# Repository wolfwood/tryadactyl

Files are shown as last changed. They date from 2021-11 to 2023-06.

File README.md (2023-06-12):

# What Is Try-A-Dactyl?
The goal of this project is to be a flexible API for generating ortholinear-ish (column-staggered) keyboards, and particularly split, concave keyboards often called [Dactyls](https://github.com/adereth/dactyl-keyboard). You can start with my preferred keyboard and modify it to your needs, or use the API to build your own 'from scratch' without the pain of re-writing the details you don't care about.

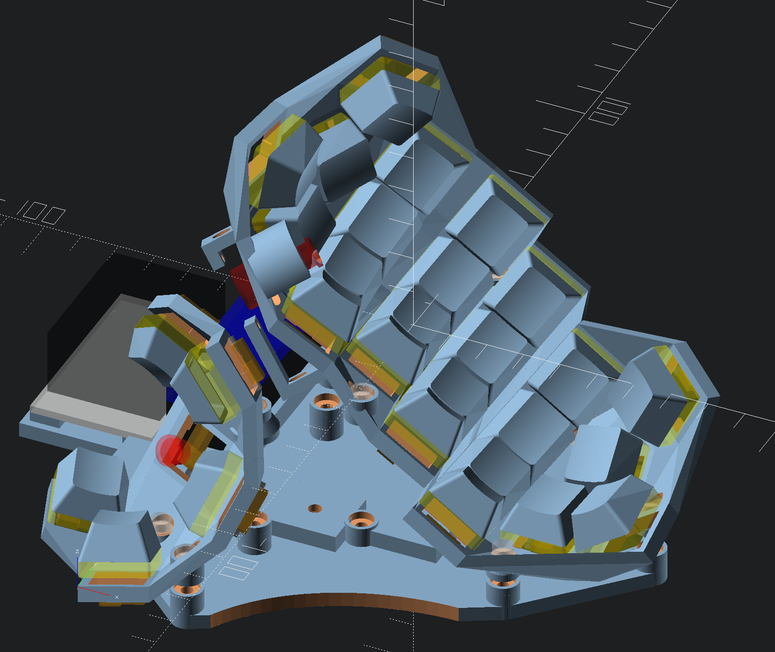
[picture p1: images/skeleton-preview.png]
skeleton-edition style preview


## Why Is TryÅdactyl Different
This project starts with the assumption that one-size does *not* fit all, and so a keyboard user will want to tune their dactyl to achieve the greatest comfort possible. In this process, a number of design-print-test iterations will be required and while the process of 3D printing can be a significant time delay, beyond a certain point its not possible to spend extra time designing and avoid the need to print and test. Given this, it makes sense to optimize the modeling software for faster iteration time at both the design and print level, and to expose both easy configuration for bootstrapping and more fine-grained control for tuning. This way you can Try All (the) Dactyls!

  * faster previews - writing in pure OpenSCAD lets us see changes as fast as possible, rather than using a generator-style binding with a more traditional programming language that must be executed (and possibly compiled) before changes will be visible
  * faster prints - support for multiple case styles allows quicker turn around with more open models like the [Dactyl Manuform Skeleton Edition](https://github.com/atsuyuki/dactyl-manuform-skeleton-edition-4x5)-inspired case, and then the ability to print the same layout with a more protected case with sidewalls when you've settled on a design
  * placement in terms of the keycap tops, not the key switch holders - control where you want your fingers to be, not where the switches go; this means you can keep the same exact layout and change from e.g. Cherry profile to DSA (provided the keycaps don't collide)
  * all parameters correspond to measurable quantities - combined with the above, makes it easier to say things like "I want to move the equals key 2 mm closer to my pinkie" and get the results you want
  * library / API style approach - gives you the tools to build what *you* want, and makes it easy to plug in different keyswitch / keycap styles without having to rewrite half the code
  * no post-processing needed - it should be easier to incorporate unanticipated additions directly in OpenSCAD than to take an *.stl* and munge it somewhere else

I also aim to document an easy approach to handwiring that both simplifies the initial process and allows easy reuse of the electronics as you switch from case to case. [You can find a brief summary here](docs/wiring.md).

## How Does My Personalized Tryadactyl Stand Out?
  * uses sculpted Cherry keycaps as though they are a flat profile
  * concave, spherical thumb cluster, with a 5-way nav switch
  * **Trackpoint!**
  * spherical "pair" of columns under pinkie and index, with lowest key in the outside column moved to the homerow, one column further out
    * on the index, this makes room for the trackpoint without cutting keycaps
	* on the pinkie this makes for a more comfortable extension of the finger to the side to press shift, rather than curling up and pressing down and out
  * recessed magnets in the base plate, to hold the keyboard firmly to an adjustable metal tray. [I documented my approach for mounting peripherals to my chair arms here](https://wolfwood.github.io/chair-arm-keyboard-mounting/).

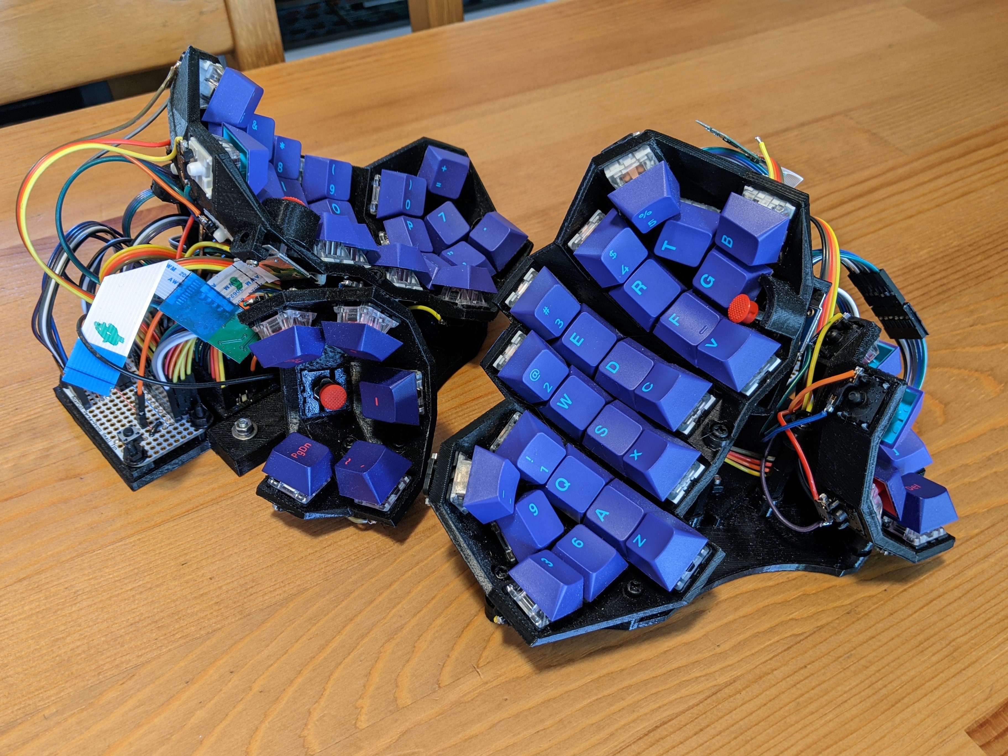
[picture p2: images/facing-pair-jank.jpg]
first full build


## Cool Software Features
  * orthogonal row/column placement styles including flat and cylindrical (cylindrical row + cylindrical column == spherical placement of thumb keys, for example)
  * pluggable support for new placement styles (spirals anyone?)
  * ability to automatically place things (like trackpoints, screws, and support struts) at the corners between keys so they don't collide with switches and keycaps, even when using complex placements
  * pluggable keycap support (add a new profile with a single function)
  * pluggable switch support
  * per-key configuration overrides
    * stick a Row 1 key next to a Row 4 key seamlessly by changing keycap profile row
    * Favorite keycaps don't come with an ortho/ergo kit? Use 'traditional' wide modifier keys with you non-row staggered design by setting a position offset.
  * multiple case styles, automatically generated base plates, and easy manual tuning of strut or wall placement
  * visual indications in preview-mode for identifying keycap collisions (including key travel, when pressed) or hotswap socket collisions with the model or each other

# Organization of the Code
These are abbreviated descriptions of what lives where. See the linked files for detailed documentation comments.

  * **Keys** - the most basic building blocks of a keyboard (you are unlikely to need these directly)
    * [key/mount.scad](key/mount.scad) - The `key_mount()` is the basic switch holder. there are also various bounding boxes around the sides of the keywell used to stitch keywells together into a switch plate, and to generate sidewalls for a case when desired.
	* [key/cap.scad](key/cap.scad) - The `keycap()` model manages caching of pre-rendered *.stl*s when possible and by default hides the caps when rendering a keyboard for printing.  `position_flat()` orients a `keycap()`, or `key_mount()` with the origin at the center of the top of the keycap. `effective_rows()` produces the data structure used to map row/column indexes to keycap profile rows used by a given layout, such as a keyboard without number row that uses only R2, R3, R4.

  * **Columns** - the main unit of organization for our designs, one or more columns per finger
  	* [column/layout.scad](column/layout.scad) - `layout_columns(rows, cols, homerow, homecol, ..., keys, wells, walls, ..., params)` is the main module exposed to the user for creating a keyboard. It creates a connected plate of `cols` key columns with `rows` rows. The `homerow` and `homecol` give the coordinates of the key that is centered on the origin. This is mostly important for curved placements. The boolean `keys` can be used to disable display of keycaps in previews, `wells` controls generation of the switch plate, and `walls` controls the creation of walls, which are independent of the switch plate. The booleans `leftwall`, `rightwall`, `topwall` and `bottomwall` control a separate way to generate simple, regular walls that are reasonable for flat keyboards with a shallow tent and tilt. A `wall_matrix` may be specified instead to give per-key control of the wall sides and distance (including multiple articulation points). The params struct is generated by the function below.
    * [column/util.scad](column/util.scad) - The function `layout_placement_params()` produces a pseudo-struct containing all the user supplied configuration parameters, for convenience. `layout_placement()` is the low level module all the higher level APIs use to uniformly place child modules at row, column coordinates, using the placement_params. The functions `create_flat_placement()` and `create_circular_placement()` create structs passed to `layout_placement_params()` for row or column alignment. The flat placement take an [x, y] pair (or vector of pairs, or vector of vector of pairs) specifying distance in millimeters. The circular placement takes a [chord, radius, angle] triplet (or vectors thereof) specifying the relationship between two points on a circle, using any two of: the the shortest-line distance between the points (a *chord*), the radius of the circle, or the angle between the two points from the center of the circle. `normalize_chord()` calculates the missing parameter from the other two, but should be automatically called anywhere a chord is accepted to sanitize the input. If a single value is provided to these functions, the spacing between successive rows or columns will be uniform. If a vector of values are provided, the distance used for each successive row or column relative to the previous can be tweaked. using a vector of vectors allows it to vary both per-row and per-column. missing rows, or columns, will be substituted with the last specified value. The `optional_vector_index()` automates this lookup-with-substitution process. `optional_index()` is the version used for scalars, like `rows`.

  * **Accessories**
    * [assembly/rest.scad](assembly/rest.scad) - `wrist_rest_base()` is the model for @crystalhand's holder for a silicone palmrest. this file invokes it and adds mounting dimples for rubber feet and a flush mount for a bar-shaped cup magnet. (**TODO** add @kennykaye style rest)
	* [assembly/trackpoint.scad](assembly/trackpoint.scad) - `install_trackpoint(row, col, ... displacement, params, ... use_shield ...)` places a mount for a trackpoint so that the stem rises through the intersection between keys nearer to the `homerow` and `homecol` of the key specified by `row` and `col`. `displacement` can be used to tweak this positioning without having to modify the `params` used for the rest of the switch plate. `h1` and `h2` can be used to move the arms of the trackpoint mount so they contact the switch plate and don't collide with the switches. `use_shield` enables a  cylindrical covering to protect the trackpoint stem extension, if the trackpoint is not fully encircled by keys.
	* [util.scad](util.scad) - utilities for hulling sets of modules while preserving their concavities; utilities for mounting magnets, rubber feet, microcontrollers, and other electronics.

  * **Keyboards**
	* [settings.scad](settings.scad) - controls various parameters mostly pertaining to key caps, switches, spacing and rendering settings
    * [assembly/util.scad](assembly/util.scad) - the `screw_mounting()` module and associated `screw_mounting_params()` function for adding screw-attached support struts between switch plate and base plate
	* [assembly.scad](assembly.scad) - my personal skeleton-edition style keyboard
	* [debug-new-walls.scad](debug-new-walls.scad) - my closed-case keyboard experimentation

# Usage
To view the keyboard assembled, run `openscad assembly.scad`. This is how I normally make edits. Within [assembly.scad](assembly.scad) the base plate is generated in debug mode which just shows the strut mount placement, so that strut heights can be manually adjusted, and so that renders are faster. To see the full keyboard, find the line `base_plate(debug=true);` and change to `false`.

For printing, the `assembly/fingers.scad`, `assembly/plate.scad` and `assembly/thumb.scad` models can be used to obtain separate parts. trying to print the whole assembly as is would be unlikely to succeed. I like to use the commandline to invoke `openscad` for renders, like the following: `openscad -q --hardwarnings --render -o things/plate.stl assembly/plate.scad`.

To validate that changes to the library code have not introduced regressions, run `make test` prior to editing (or after a `git stash`), which will generate reference *.stl*s for later comparison. Run `make test` again after editing to see if the tests still produce identical *.stl*s. New tests should be added when new positioning functions, keycap profiles, or other features are introduced. The tester models should also be useful to those who might like to print a smaller model to consider the feel of a given column shape without wasting time and material printing a full keyboard.

Right now testing is a bit fiddly. Edit `testers/wrapper.py` to point `SCAD_EXE` at a nightly build of openscad, which has the *sort-stl* feature. Even with that, *.stl* files aren't always consistent. The alternative approach also has issues. Blog post incoming :)

# FAQs
#### Q
  Why not just use a flat keycap profile and save yourself a lot of work?

#### A
  0. Using a flat profile doesn't actually solve the problem. For example, when you do cylindrical placement of the switch holders, rather than the keycap top surfaces, the radius does not correspond to measurements of the fingers and their movement. The radius is longer because the height of the switch and keycap can be a sizable percentage of the finger length. Rather than calculating this offset manually, it makes sense for the software to make the compensation for you.

  1. I'm not aware of a cylindrical topped (rather than spherical) flat MX profile, which I prefer.

  2. Sculpted profiles tend to have angled sides, and top surfaces that are noticeably smaller than a full 1u footprint, which lets you pack them a bit more tightly if you aren't looking for a full 19.05 mm spacing between keys. This also seems particularly important for the spherical key placement i use, because its more at risk of keycap collisions than cylindrical. However, I haven't yet investigated the spherical placement with a flat profile, so maybe it's less of a concern than it seems.

  3. Many colorways are limited to specific (sculpted) profiles. I started this project after being completely blown away by the [GMK Copper renders](https://geekhack.org/index.php?PHPSESSID=6mre0fhdltin70p68o5i6feekgqu2082&action=dlattach;topic=102917.0;attach=229851;image), for example.

  4. Flexibility: my design can accommodate flat profiles. It may even give the most pleasing results that way. It can also accommodate sculpted profiles. It could even be used to add a sculpted effect to a flat profile (or change the sculpt of a sculpted profile). To each their own, as they say.

  5. Cherry profile R3 has a lower vertical height that DSA or XDA. Obviously chocs are a superior choice for low profile switches, but I don't like linear switches and I love my Kailh Speed Copper switches, so Cherry profile helps me shave off some height.

# TODO
  * key (profile & switch/well) configuration architecture
    - [ ] add and test SA profile support
    - [ ] add and test DSA profile support
    - [ ] parameterize switch (choc, void, ???)
	  - [ ] use this to support SKRH and RKJXS nav switches instead of profile row?
	  - [x] expand `mxstem()` to incorporate switch type
	  - [x] how to generalize `innerdia`, `outerdia` and `thickness`
      - [ ] separate keywell use of `spacer()` from assembly.scad level use
        - [ ] think about automatic decisions about using minimum keywell dimension vs being wide enough to prevent hull from colliding with 1U keycap vs wide keycap support vs being as wide as whatever the keyspacing is to maybe avoid hulling if adjacent key is the same profile and has identical positioning (tent/tilt/offset etc.)
	- [ ] test traditional modifier key support
	  - [ ] add concept of key width or is using offset good enough?
  * columns
    - [ ] document layout_columns arguments
	- [ ] spiral placement
	- [ ] figure out how to connect 2 rectangles (faces of a keywell) in 3D space without hull ([functional OpenSCAD](https://github.com/thehans/FunctionalOpenSCAD) seems like a good bet, or BOSL2?)
	  - [ ] alternatively use the corner sphere bounding boxes for _everything_ to guarantee thickness and accept the cost (and figure out how to avoid colliding with keycap)
  * case
    - [ ] finish closed case
	  - [ ] join the walls of each finger's switch plate
	  - [ ] consider bridging over some keys on the sides
	  - [ ] generate closed case base plate
	- [ ] add cylindrical perimeter to skeleton-edition case
	- [ ] support raised perimeter bezel
	- [ ] more wall code cleanup
	- [ ] hack up and test a @kennykaye-esque palmrest? use JellyTitan magnetic feet?
  * general
    - [x] reorganize code into directories?
	- [ ] re-locate util functions
	- [x] rename `keywell()` to ???`switch_holder()`??? to reflect that keywell is generally accepted to mean concavity
    - [ ] decide how multiple case style support and rendering of individual parts can be generalized

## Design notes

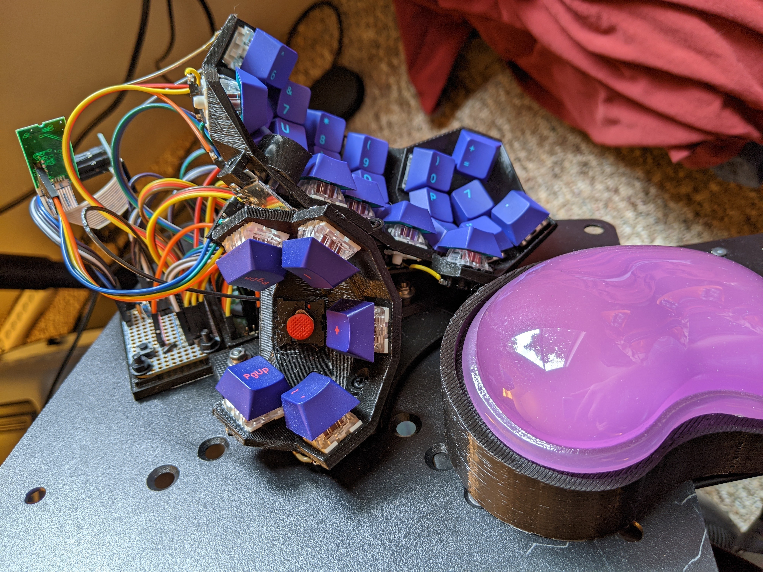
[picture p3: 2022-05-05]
images/jank.jpg

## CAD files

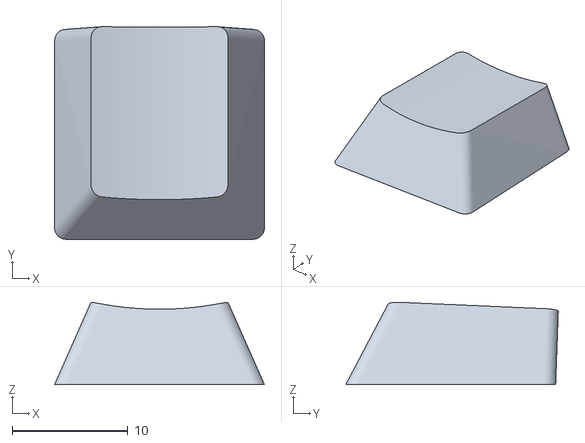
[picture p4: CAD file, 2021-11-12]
key/prerendered/cherry/2.stl
18.2 x 18.4 x 7.13

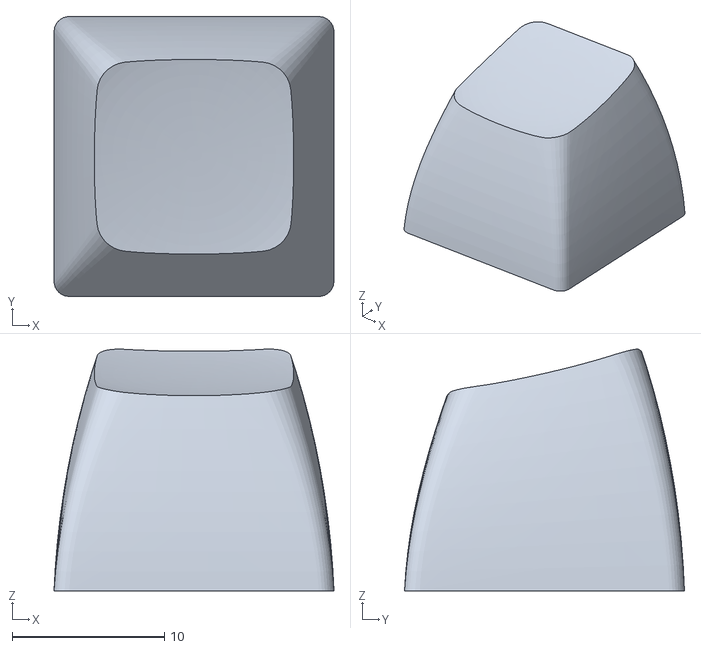
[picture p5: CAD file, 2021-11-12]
key/prerendered/sa/1.stl
18.4 x 18.4 x 15.9

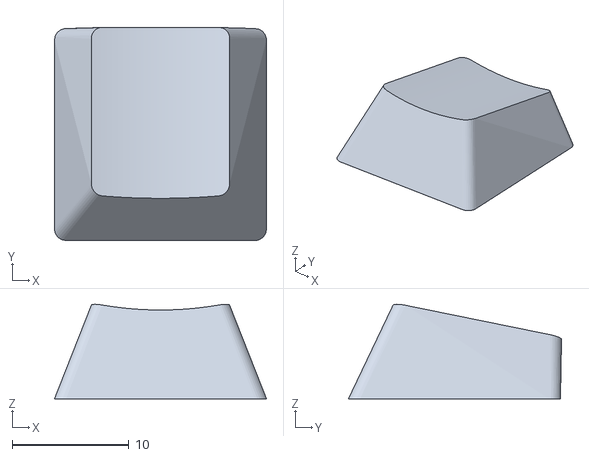
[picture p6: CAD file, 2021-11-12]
key/prerendered/cherry/5.stl
18.2 x 18.3 x 8.10

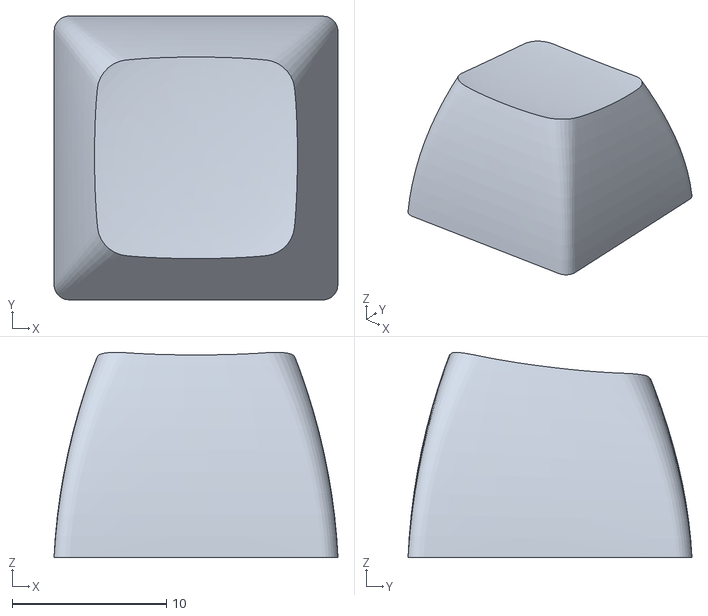
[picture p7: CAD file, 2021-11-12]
key/prerendered/sa/4.stl
18.4 x 18.4 x 13.3

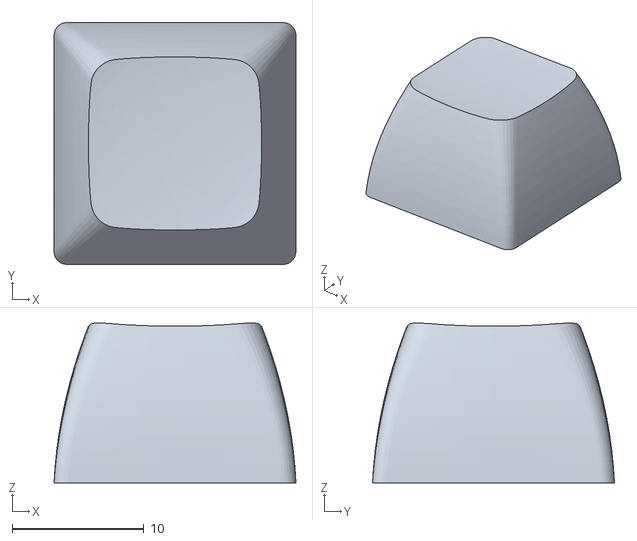
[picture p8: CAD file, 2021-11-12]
key/prerendered/sa/5.stl
18.4 x 18.4 x 12.2

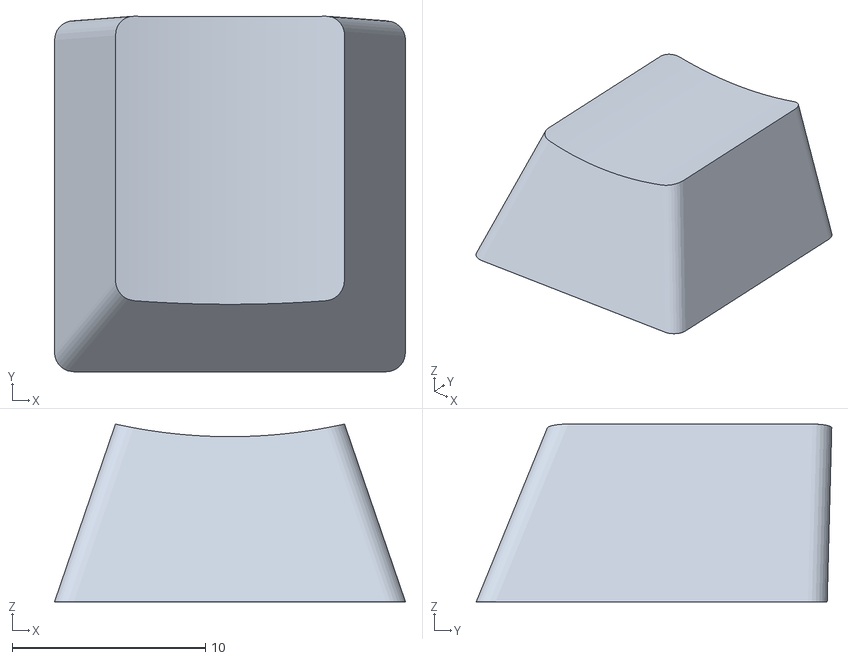
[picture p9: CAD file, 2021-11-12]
key/prerendered/cherry/1.stl
18.2 x 18.4 x 9.20

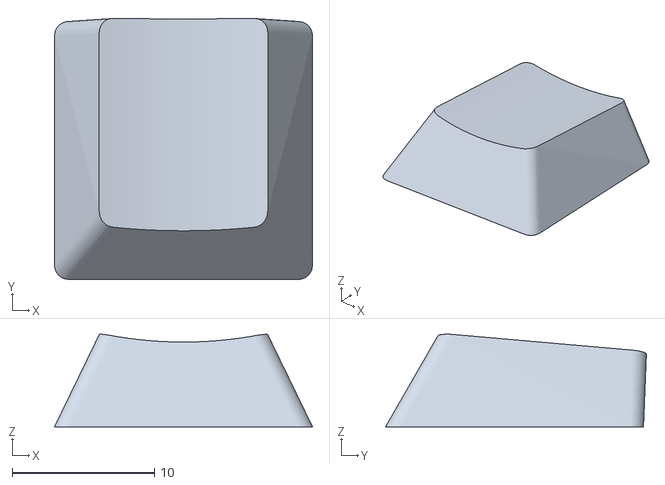
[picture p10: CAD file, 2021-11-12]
key/prerendered/cherry/3.stl
18.2 x 18.4 x 6.52

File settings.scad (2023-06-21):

/* keycaps */
_profile = "cherry";

// the height of the bottom of the keycap over the key_mount.
// a property of the keycap but I couldn't think fo a better name.
// shouldn't need to override this directly, but you can.
//_stem_height = 6.1;

// keycap render settings

/* Pre-rendered keycaps are recommended as they should be much faster, and remove the dependency on KeyV2.
 * However they lose the distinctive coloring. Also, pre-renders may be missing. Used in both previews and renders.
 */
_prerendered_keycaps = true;

// if not pre-rendering, these options turn down the fidelity so that previews/renders don't take so long
_fast_keycap_preview = true;
_fast_keycap_render = false;

// don't show keycaps in renders. we don't want keys when 3D printing, also they block the view and can be slow
_disable_keycap_render = true;


/* keyswitch */
// switch style is "mx", "choc".
// can be inferred from profile
//_switch_style= "choc";

// if using mx switches, are they speed switches (lower travel)?
//_mx_speed = true;

// how far the key switch can depress (only for visual indication, doesn't affect the keyboard)
// can be inferred from switch type
//_switch_travel = 4.0;


/* key_mount parameters */
// innerdia is the (square) hole for the switch
// outerdia is the the minimum structural support
_mx_innerdia = 13.9;
_mx_outerdia = 17;

_choc_innerdia = 13.8;
_choc_outerdia = 15.5;

// key plate thickness
// can be inferred from switch type
//_thickness=4; // blanket override... probably unnecessary

_mx_thickness = 4;
_choc_thickness = 3;

// MX cutout params
function mx_tab_offset() = 1.2; // how far from the top the switchholders start
function mx_tab_depth() = 0.6; // how far tabs stick out
function mx_tab_width() = 5;

function choc_tab_offset() = 1.2; // how far from the top the switchholders start
function choc_tab_depth() = 0.2; // how far tabs stick out

function mx_and_choc()=false;

_epsilon = .001; // smallest meaningful overlap, used when avoiding coincident faces

// the footprint of the keycaps.
// defines how close key_mounts can be, but mostly used for outer perimeters.
_mx_min_spacing = 18.4;
_choc_min_spacing = 18;

// how much room we need for switchpins, hotswaps, etc.
// used to cut into trackpoint mount supports
function switch_clearance() = 3;


/* side wall width */
_wall_width=2.5;

// extra space between the key mount and an ajoining wall, in x and y
_wall_extra_room = [0,0]; //[5,3];


// bounds
//highest_high=40;
//XXX  eliminate by placing bottom of plate at Z=0
function lowest_low() = 60;

// Do Not Edit Below This Line

function profile(override) =
  !is_undef(override) ? override :
  !is_undef($profile) ? $profile :
  _profile;

function profile_is_uniform() =
  profile() == "dsa" || profile() == "g20" || profile() == "lpx";


function stem_height() =
  !is_undef($stem_height) ? $stem_height :
  !is_undef(_stem_height) ? _stem_height :
  profile() == "cherry" ? 6.1 :
  profile() == "sa" ? 6.8 :
  profile() == "lpx" ? 5 :
  assert(false, "unrecognized keycap profile");


function prerendered_keycaps() = !is_undef($prerendered_keycaps) ? $prerendered_keycaps : _prerendered_keycaps;
function fast_keycap_preview() = !is_undef($fast_keycap_preview) ? $fast_keycap_preview : _fast_keycap_preview;
function fast_keycap_render() = !is_undef($fast_keycap_render) ? $fast_keycap_render : _fast_keycap_render;
function disable_keycap_render() = !is_undef($disable_keycap_render) ? $disable_keycap_render : _disable_keycap_render;

function switch_type() =
  !is_undef($switch_type) ? $switch_type :
  !is_undef(_switch_type) ? _switch_type :
  profile() == "lpx" || profile() == "mbk" || profile() == "cs" || profile() == "mcc" ? "choc" :
  profile() == "cherry" || profile() == "sa" || profile() == "dsa" || profile() == "g20" ? "mx" :
  assert(false, str("unknown profile '", profile(), "' cannot deduce switch_type"));

function mx_speed() =
  !is_undef($mx_speed) ? $mx_speed :
  !is_undef(_mx_speed) && _mx_speed;

function switch_travel() =
  !is_undef($switch_travel) ? $switch_travel :
  !is_undef(_switch_travel) ? _switch_travel :
  switch_type() == "mx" ? mx_speed() ? 3.5 : 4.0 :
  switch_type() == "choc" ? 3.0 :
  assert(false, str("unknown switch_type '", switch_type()));

function innerdia() =
  !is_undef($innerdia) ? $innerdia :
  switch_type() == "mx" || (mx_and_choc() && switch_type() == "choc") && !is_undef(_mx_innerdia) ? _mx_innerdia :
  switch_type() == "choc" && !is_undef(_choc_innerdia) ? _choc_innerdia :
  assert(false, str("please define an innerdia for: ", switch_type()));

function outerdia() =
  !is_undef($outerdia) ? $outerdia :
  switch_type() == "mx" && !is_undef(_mx_outerdia) ? _mx_outerdia :
  switch_type() == "choc" && !is_undef(_choc_outerdia) ? _choc_outerdia :
  assert(false, str("please define an outerdia for: ", switch_type()));

function spacer() =
  !is_undef($spacer) ? $spacer :
  switch_type() == "mx" ? _mx_min_spacing - outerdia() :
  switch_type() == "choc" ? _choc_min_spacing - outerdia() :
  assert(false, str("please define an spacer for: ", switch_type(), " or: ", profile()));

function thickness() =
  !is_undef($thickness) ? $thickness :
  !is_undef(_thickness) ? _thickness :
  switch_type() == "mx" ? _mx_thickness :
  switch_type() == "choc" ? _choc_thickness :
  assert(false, "please define a key plate thickness");

function wall_width() =
  !is_undef($wall_width) ? $wall_width :
  !is_undef(_wall_width) ? _wall_width :
  assert(false, "please defined a wall_width");

function wall_extra_room() =
  !is_undef($wall_extra_room) ? $wall_extra_room :
  !is_undef(_wall_extra_room) ?
  !is_list(_wall_extra_room) ? [_wall_extra_room, _wall_extra_room]
  : _wall_extra_room :
  [0,0];


function epsilon() =
  !is_undef($epsilon) ? $epsilon :
  !is_undef(_epsilon) ? _epsilon :
  assert(false, "please define an _epsilon value");

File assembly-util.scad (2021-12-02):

include <settings.scad>;
use <column-util.scad>;


//keys for param "dictionary"
height_enum = "a";
strut_dia_enum = "b";
screw_dia_enum = "c";
washer_dia_enum = "d";
headroom_enum = "e";
footroom_enum = "f";
spacer_enum = "g";
stay_upright_enum = "h";
//tent_enum = "i";
displacement_enum = "j";
row_enum = "k";
col_enum = "l";
layout_params_enum = "m";
offsets_enum = "n";


// diy stuct for marshalling all the params together
// cylinders are described with a 2D vector, x as diameter and y as height
function screw_mounting_params(row, col, height=20, strut_dia=6.5, screw_dia=3.2, washer_dia=6.4,
			       headroom=[[0,0],[2,7]], footroom=[2,2], spacer=3, stay_upright=true, displacement=[0,0,-15], offsets=[0,0,0], layout_params=default_layout_placement_params()) =
  [[height_enum, height],
   [strut_dia_enum, strut_dia],
   [screw_dia_enum, screw_dia],
   [washer_dia_enum, washer_dia],
   [headroom_enum, headroom],
   [footroom_enum, footroom],
   [spacer_enum, spacer],
   [stay_upright_enum, stay_upright],
   //[tent_enum, tent],
   [displacement_enum, displacement],
   [offsets_enum, offsets],
   [row_enum, row],
   [col_enum, col],
   [layout_params_enum, layout_params]];

default_screw_mounting_params = screw_mounting_params();


module screw_mounting_blank(params, idx) {
  strut_dia = match(strut_dia_enum, params);
  screw_dia = match(screw_dia_enum, params);
  washer_dia = match(washer_dia_enum, params);
  headroom = optional_vector_index(match(headroom_enum, params), idx);
  footroom = optional_vector_index(match(footroom_enum, params), idx);
  spacer = optional_index(match(spacer_enum, params), idx);

  rotate([idx*180,0,0]) {
    headroom_dia = washer_dia + headroom.x;
    footroom_dia = strut_dia + footroom.x;
    // envelops screwhead and washer
    cylinder(h=headroom.y, d=headroom_dia);
    /* washer sit on this, and it 'spaces' out the cuts for the washer and the strut if we need to
     *  avoid cutting into switch plate too deeply */
    translate([0,0,-spacer]) {
      cylinder(h=spacer, d2=headroom_dia, d1=footroom_dia);
      // envelops strut to provice a bit more stability
      translate([0,0,-footroom.y]) {
	cylinder(h=footroom.y, d=footroom_dia);
      }
    }
  }
}

module mount_bounding_box(z, thickness, mounting_params=default_screw_mounting_params) {
  let(row=match(row_enum, mounting_params),
      col=match(col_enum, mounting_params),
      displacement=match(displacement_enum, mounting_params),
      offsets=match(offsets_enum, mounting_params),
      layout_params=match(layout_params_enum, mounting_params),
      strut_dia = match(strut_dia_enum, mounting_params),
      washer_dia = match(washer_dia_enum, mounting_params),
      headroom_0 = optional_vector_index(match(headroom_enum, mounting_params), 0),
      headroom_1 = optional_vector_index(match(headroom_enum, mounting_params), 1),
      footroom_0 = optional_vector_index(match(footroom_enum, mounting_params), 0),
      footroom_1 = optional_vector_index(match(footroom_enum, mounting_params), 1),
      x = max(strut_dia + max(headroom_0.x, headroom_1.x), washer_dia + max(footroom_0.x, footroom_1.x))
      ){

    translate([0,0,z])
      linear_extrude(thickness)
      projection()
      layout_placement(row, col, params=layout_params, offsets=offsets, displacement=displacement,
		       corners=true, flatten=false, stay_upright=true)
      cube([x,x,1],center=true);
  }
}

module screw_mounting(row,col,height, displacement,
		      row_spacing, col_spacing, profile_rows, homerow, homecol, tilt, offsets,
		      mounting_params=default_screw_mounting_params,
		      layout_params, idx=-1, clearance=true, blank=false) {

  module clearance(washer=[6, .55], screwhead=[5.55, 2.55], indicator=0) {
    color("silver", .3) {
      cylinder(d=washer.x, h=washer.y);
      translate([0,0,washer.y]) cylinder(d=screwhead.x, h=screwhead.y);
      if (indicator != 0) {
	translate([0,0,washer.y+screwhead.y]) difference() {
	  cylinder(d=indicator+4, h=.1);
	  cylinder(d=indicator, h=.1);
	}
      }
    }
  }

  let(row=match_override(row_enum, mounting_params, row),
      col=match_override(col_enum, mounting_params, col),
      height=match_override(height_enum, mounting_params, height),
      displacement=match_override(displacement_enum, mounting_params, displacement),
      offsets=match_override(offsets_enum, mounting_params, offsets),
      layout_params=match_override(layout_params_enum, mounting_params, layout_params),
      strut_dia = match(strut_dia_enum, mounting_params),
      screw_dia = match(screw_dia_enum, mounting_params),
      washer_dia = match(washer_dia_enum, mounting_params),
      spacer_0 = optional_index(match(spacer_enum,mounting_params), 0),
      spacer_1 = optional_index(match(spacer_enum,mounting_params), 1),
      headroom_0 = optional_vector_index(match(headroom_enum,mounting_params), 0),
      headroom_1 = optional_vector_index(match(headroom_enum,mounting_params), 1)
      ){

    assert(height==6 || height==10 || height==12 || height==15 || height==16 || height==18 || height==20 ||
	   height==21 || height==22 || height==24 || height==25 || height==26 || height==27 || height==28 || height>=30,
	   "Height must be a combination of 6, 10, 15 and 20 mm struts");

    difference() {
      union() {
	layout_placement(row, col, params=layout_params,row_spacing=row_spacing, col_spacing=col_spacing, profile_rows=profile_rows, homerow=homerow, homecol=homecol, tilt=tilt, offsets=offsets, displacement=displacement,corners=true, flatten=false, stay_upright=true) {
	  $fn=60;

	  if(idx != 1)
	    screw_mounting_blank(mounting_params,0);

	  if (idx != 0)
	    translate([0,0,-height-spacer_0-spacer_1]) {
	      screw_mounting_blank(mounting_params,1);
	    }
	}

	children();
      }

      if (!blank) {
	layout_placement(row, col, params=layout_params, row_spacing=row_spacing, col_spacing=col_spacing, profile_rows=profile_rows, homerow=homerow, homecol=homecol, tilt=tilt, offsets=offsets, displacement=displacement,corners=true, flatten=false, stay_upright=true) {
	  $fn=60;
	  cylinder(h=height,d=washer_dia);

	  let(z=height+spacer_0+spacer_1) {
	    translate([0,0,-(z+.1)]) cylinder(h=z+2*.1, d=screw_dia);
	    translate([0,0,-(z+height+7)]) cylinder(h=height+7, d=washer_dia);
	  }
	  let(z=height) {
	    translate([0,0,-(z+spacer_0)]) cylinder(h=z, d=strut_dia);
	  }
	}
      }
    }

    if ($preview && clearance && !blank) {
      layout_placement(row, col, params=layout_params, row_spacing=row_spacing, col_spacing=col_spacing, profile_rows=profile_rows, homerow=homerow, homecol=homecol, tilt=tilt, offsets=offsets, displacement=displacement,corners=true, flatten=false, stay_upright=true) {
	$fn=60;
	if(idx != 1)	  clearance();
	if(idx != 0)
	  translate([0,0,-(height+spacer_0+spacer_1)]) rotate([180,0,0]) clearance(indicator=washer_dia+headroom_1.x);
      }
    }
  }
}

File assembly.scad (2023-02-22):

use <settings.scad>;
use <key/cap.scad>;
use <column/util.scad>;
use <column/layout.scad>;
use <assembly/trackpoint.scad>;
use <assembly/util.scad>;


rows=4;
cols=2;

homerow=2;
profile_rows=effective_rows(rows,homerow);
tilt=[-3,0,0];
tent=[0,32,0];
row_chord = [14.5,25,0];

// Akko cherry PBT neesds a bit more space
tight_cylindrical_row =[row_chord+[.5/2,0,0],
			 row_chord+[.5,0,0],
			 row_chord,
			 row_chord+[.5,0,0]];


tight_spherical_row = [row_chord+[5.2,0,0],
		       row_chord+[4.75,0,0],
		       row_chord+[4.5,0,0],
		       row_chord+[8.6,0,0]];
tight_spherical_col = [[row_chord+[-1.8,0,0]],
		       [row_chord+[.9,0,0]],
		       [row_chord+[0,0,0]],
		       [row_chord+[-.5,0,0]]];
spherical_z = [4,30,0,0];

index_keys= true;
index_pos = [-(outerdia()+4),-4,6];
index_tent = [0,0,5];
index_tilt = [0,0,0];
index_rows= [rows, rows-1, 1];
index_cols=cols;
index_placement_params =
  layout_placement_params(homerow=[homerow,homerow,0], homecol=0,
			  row_spacing=create_circular_placement([tight_cylindrical_row, tight_spherical_row, [row_chord]]),
			  col_spacing=create_circular_placement(tight_spherical_col, z_correct=spherical_z),
			  profile_rows=[profile_rows,profile_rows,[4]],
			  tent=index_tent+tent, tilt=index_tilt, position=index_pos);

index_mountings = [screw_mounting_params(row=0, col=0, height=60, layout_params=index_placement_params,
					 displacement=[5,-1,-23], offsets=[0,0,-1],
					 headroom=[[10,0], [2,10]], footroom=[[12, 2], [2, 2]]),
		   //screw_mounting_params(row=1, col=0, height=50, layout_params=index_placement_params)
		   screw_mounting_params(row=1, col=0, height=40, displacement=[-11, -1.8, -17],
					 headroom=[[1,2.6], [2,10]], layout_params=index_placement_params)
		   /*screw_mounting_params(row=3, col=0, height=50, layout_params=index_placement_params,
					 headroom=[[1,0],[2,7]],
					 displacement=[2,5,-20])*/
		   ];


middle_keys = true;
//middle_offset = [[0,0,0], [0,4,1]];
middle_offset = [0,5,0];
ring_offset=[1,-5,-1];
middle_rotation = [0,0,0];
middle_placement_params =
  layout_placement_params(homerow=homerow, homecol=1,
			  row_spacing=create_circular_placement(tight_cylindrical_row),
			  col_spacing=create_flat_placement(outerdia()+spacer()),
			  profile_rows=profile_rows,
			  offsets=[ring_offset, middle_offset], tent=tent, tilt=middle_rotation+tilt);
middle_mountings = [screw_mounting_params(row=0, col=0, height=30, headroom=[[1,3],[2,7]], footroom=[[2,0],[2,2]],
					  layout_params=middle_placement_params,
					  /*displacement=[1.3,.4,-15],*/displacement=[0,1.6,-15-3], offsets=[0,0, -4]),
		    screw_mounting_params(row=1, col=1, height=20, layout_params=middle_placement_params,
					  displacement=[15.5,-2,-15.5], headroom=[[2,2],[2,7]],
					  offsets=middle_offset+[0,0,-1]),
		    screw_mounting_params(row=3, col=0, height=35, headroom=[[2,2],[2,7]],
					  layout_params=middle_placement_params,
					  displacement=[-7.5,-1.5,-17], offsets=[0,0,0])
		    ];


pinkie_keys = true;//[[false],[true],[false],[false]];
pinkie_pos = [outerdia()+spacer()+20+2,-23,4];
pinkie_tent = [0,0,-2];
pinkie_tilt = [3,0,0];
pinkie_placement_params =
  layout_placement_params(homerow=homerow, homecol=1,
			  row_spacing=create_circular_placement([tight_spherical_row,
 								 [row_chord]]),
			  col_spacing=create_circular_placement(tight_spherical_col, z_correct=spherical_z),
			  profile_rows=[/*[4],*/profile_rows,profile_rows],
			  offsets=[0,0,0], tent=tent+pinkie_tent, tilt=pinkie_tilt+tilt,
			  position=pinkie_pos);

pinkie_mountings = [screw_mounting_params(row=0, col=0, height=10,
					  displacement=[2,-5.8,-15.3],
					  offsets=[0,0,-2],
					  layout_params=pinkie_placement_params),
		    screw_mounting_params(row=1, col=0, height=10, layout_params=pinkie_placement_params,
					  displacement=[28,14,-15]),
		    screw_mounting_params(row=2, col=0, height=6,
					  displacement=[5,3,-14],
					  layout_params=pinkie_placement_params)
		    ];

thumb_keys= true;
thumb_pos = index_pos + [-1.5*(outerdia()+spacer())+30,-3.5*(outerdia()+spacer())-1,-30];
thumb_tilt = [10,-100,25];
thumb_tent = tent+[0,0,-5];
thumb_row_chord_sides = [30, 25, 0];
thumb_row_chord_center = [14.5, 0, 60];
thumb_placement_params =
  layout_placement_params(homerow=1//[0,1,0]
			  , homecol=1,
			  row_spacing=create_circular_placement([[thumb_row_chord_sides],
								 [thumb_row_chord_center],
								 [thumb_row_chord_sides]]),
			  col_spacing = create_circular_placement([[[17,16,0]],[[20,20,0]]],z_correct=60),
			  profile_rows=[[2,3],["SKRH",3],[2,1]],
			  tent=thumb_tent, tilt=thumb_tilt,
			  position=thumb_pos);

thumb_mountings = [screw_mounting_params(row=0, col=1, height=6, displacement=[4,6,-13],
					 layout_params=thumb_placement_params),
		   screw_mounting_params(row=0, col=1, height=6, displacement=[2,-13,-16],
					 headroom= [[2,2],[2,10]], footroom=[[2,2],[2,1]],layout_params=thumb_placement_params),
		   screw_mounting_params(row=0, col=0, height=30, offsets=[0,0,0], displacement=[0,-4.8,-16.0],
					 headroom=[[2,3],[2,10]], footroom=[[6,2],[2,2]],
					 layout_params=thumb_placement_params)
		];

/*
  thumb_keys= [false,true,false];
thumb_pos = index_pos + [-1.75*(outerdia()+spacer()),-2.5*(outerdia()+spacer())+7,-15 -5];
thumb_row_chord_sides = [20.5,500,0];
thumb_row_chord_center = [14.5, 50,0];
thumb_placement_params =
  layout_placement_params(homerow=0, homecol=1,
			  row_spacing = create_flat_placement(19.1),
			  col_spacing = create_circular_placement([[[14,16,0]],[[18,32,0]]],z_correct=0),
			  profile_rows=[[3,2],[3,"SKRH"],[1,2]],
			  tent=tent+[-10,0,0], tilt=[20,-80,0],
			  position=thumb_pos);

thumb_mountings = [screw_mounting_params(row=0, col=1, height=10, displacement=[-0.5,-13,-15],
					 headroom= [[1,0],[2,7]], layout_params=thumb_placement_params),
		   screw_mounting_params(row=0, col=1, height=10, displacement=[1,6,-15],
					 layout_params=thumb_placement_params),
		   screw_mounting_params(row=0, col=0, height=30, offsets=[0,0,0], displacement=[4,0,-21],
					 headroom=[[2,3],[2,7]], footroom=[[7,2],[2,2]],
					 layout_params=thumb_placement_params)
		];
*/

/*thumb_pos = index_pos + [-2*(outerdia()+spacer()),-2.5*(outerdia()+spacer())+7+1,-15 -5];
thumb_row_chord_sides = [20.5,40,0];
thumb_row_chord_center = [14.5,32,0];
thumb_placement_params =
  layout_placement_params(homerow=0, homecol=1,
			  row_spacing=create_circular_placement([[thumb_row_chord_sides],
								 [thumb_row_chord_center],
								 [thumb_row_chord_sides]]),
			  col_spacing = create_circular_placement([[[12,14,0]],[[14,14,0]]],z_correct=21),
			  profile_rows=[[3,2],[3,"SKRH"],[3,2]],
			  tent=tent+[-10,0,0], tilt=[normalize_chord(thumb_row_chord_center)[2]+10,-60,0],
			  position=thumb_pos);

thumb_mountings = [screw_mounting_params(row=0, col=1, height=10, displacement=[-0.5,-3,-16],
					 layout_params=thumb_placement_params),
		   screw_mounting_params(row=0, col=1, height=10, displacement=[1,15,-15],
					 layout_params=thumb_placement_params),
		   screw_mounting_params(row=0, col=0, height=35, offsets=[0,0,0], displacement=[6.5,0,-20],
a					 headroom=[[2,3],[2,7]],
					 layout_params=thumb_placement_params)
		];
*/
function tail(v) = assert(is_list(v)) len(v) == 2 ? [v[1]] : [ for (i = [1:len(v)-1]) v[i]];

module apply_screw_mountings(params, idx=0) {
  assert(is_list(params));

  screw_mounting(mounting_params=params[0], idx=idx)
    if (len(params) == 1) {
      children();
    } else {
      apply_screw_mountings(tail(params)) children();
    }
}
module mounted_thumb(keys=true) {
  let(rows=2//[1,2,1]
      ,cols=3) {
    apply_screw_mountings(params=thumb_mountings) {
      layout_columns(rows=rows, cols=cols, params=thumb_placement_params,
		     keys=false, perimeter=true, reverse_triangles=false);
      *hull() {
	layout_placement(0,2, params=thumb_placement_params) key_mount_bounding_box(y=1, header=true, leftside=true);
     	layout_placement(0,0, params=thumb_placement_params) key_mount_bounding_box(y=1, header=true, rightside=true);
      }
      hull() {
	layout_placement(0,1, params=thumb_placement_params) key_mount_bounding_box(y=1, header=true);
	layout_placement(0,2, params=thumb_placement_params) key_mount_bounding_box(y=1,x=1, header=true, leftside=true);
      }
      hull() {
	layout_placement(0,1, params=thumb_placement_params) key_mount_bounding_box(y=1,x=1, header=true);
	layout_placement(0,2, params=thumb_placement_params) key_mount_bounding_box(y=1,x=1, header=true, leftside=true);
     	layout_placement(0,0, params=thumb_placement_params) key_mount_bounding_box(y=1,x=-1, header=true, rightside=true);
      }
    }
    layout_columns(rows=rows, cols=cols, params=thumb_placement_params,
		   keys=keys?thumb_keys:false, wells=false);
  }
}
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

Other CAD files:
key/prerendered/cherry/4.stl
key/prerendered/sa/3.stl
key/prerendered/sa/2.stl
column-layout.scad
assembly/fingers.scad
assembly/plate.scad
assembly/rest.scad
assembly/thumb.scad
assembly/trackpoint.scad
assembly/tripod.scad
assembly/unsplit-bracket.scad
assembly/util.scad
column-util.scad
column/layout.scad
column/util.scad
debug-new-walls.scad
debug.scad
fingers.scad
key/cap.scad
key/mount.scad
key/prerendered/cherry/key.scad
key/prerendered/sa/key.scad
keycap.scad
keywell.scad
plate.scad
testers/cylindrical-tester.scad
testers/flat-cherry-tester.scad
testers/offset-tester.scad
testers/spherical-tester.scad
testers/split-ortho-tester.scad
testers/thumbbowl-tester.scad
testers/tubular-tester.scad
testers/unit-tester.scad
testers/wrapper.scad
trackpoint.scad
util.scad

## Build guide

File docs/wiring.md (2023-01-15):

# Handwiring a Tryadactyl

This is how I wire up my keyboard so that everything is socketed and reusable as the case design evolves.

## Parts

  - [6" Raw, socketed, jumper wire ribbons](https://www.adafruit.com/product/3141) (you can also use the 12" version and remove the individual housings, or use as is)
  - [.1" pitch Small Single Row Wire Housing Pack for DIY Jumper Cables](https://www.adafruit.com/product/3145) (there's only 10 of each size so if you have 6 four row columns on each side, like I do, you might want to supplement with [a big pack of strictly 4 pin housings](https://www.amazon.com/gp/product/B00R5FOZW2/))
  - [.1" pitch permaproto board](https://www.adafruit.com/product/1214).
  - [.1" pitch break-away header pins](https://www.adafruit.com/product/392)
  - Kailh hotswap sockets (MX or Choc, to match your choice of switch) can be found from many online keyboard shops, or you can get MX v2 sockets from Kailh/Kaihua on aliexpress.

## Summary
 
First, I solder header pins on my microcontroller facing up (pins on ther same side as the components and the silkscreen pin labels).  This lets the controller sit flat and snug in the 3D printed holder in the base plate. If you plan on using the controllers with a more standard keyboard PCB you might need pins on the other side.
 
Then I cut off the ends of two 4-wire ribbons of raw jumper (or cut a 12" ribbon so longer and shorter sides are useful for different columns) and solder each to one side of a column's worth of hotswap sockets. Then cap the jumpers with a housing so it's easy to connect as a unit. Don't make the ribbons too short, you never knows how the design will evolve. Repeat for every column on both halves, and for the thumbs.
 
Finally, I solder a bunch of headers to a permaproto board to act as ground distribution (connect to ground on your microcontroller). This also makes a good place for I2C pull up resistors, a reset switch and my trackpoint reset circuit.

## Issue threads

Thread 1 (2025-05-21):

Assembly example seem incomplete/to contain errors?

UsernameDontMatter5, 2025-05-21:
Hello wolfwood. I tried to download OpenSCAD and open the assembly file to check out your project, but some things seem incorrect.

1. The top keys for the middle finger and ring finger overlap with the keys below, creating impossible geometry. I think the mounting holes for them got shifted down somewhere along the line?
2. There seem to be some issues with different assets in the scene. A box on the side is rotated peculiarly,  I'm not seeing a base plate like in your preview image on the repository, and perhaps other stuff is missing too

I have no experience whatsoever with OpenSCAD, so perhaps my knowledge is simply lacking here, but I'm not really in a position to learn OpenSCAD from scratch at the moment to understand all the intricacies and fix mistakes. I love what you've made here and I would very much like like an 'out of the box' sample that simply works, if possible. Could you have a look if the current files are correct? Cheers :)

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

wolfwood, 2025-05-21:
the plate is displayed in debug mode by default to speed up rendering. you can use _assembly/plate.scad_ to render it or find the line `base_plate(debug=true);` and change to false.

that set of magnet mounts is intentional, it allows the use to switch between tented and vertical typing orientations.

I will take a look at the key overlap.

UsernameDontMatter5, 2025-05-22:
Thanks for taking the time!

I had another look, and with the base rendered in, the magnet mount's presence does make more sense. Guess it really was my lack of knowledge of the software and your design :)

There are some other questions about the project I might want to ask, though they aren't really 'issues' worth logging here like the key overlap, mostly some general inquiries. Is there another place where I can reach out to you that might be more convenient to talk? Or do you prefer me to just say my points in this thread still?

wolfwood, 2025-05-23:
I'm `w0lfwood` on discord if that works

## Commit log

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2021-07-18 single piece case, with updated fitting parameters from first print
    [keywell.scad, util.scad]
2021-07-22 make design more dynamic
    use hulls to join offset_column_pair, to join column hulls, and to generate column_pair sides
    [keywell.scad]
2021-08-18 all the components complete
    [keywell.scad, rest.scad]
2021-09-10 first pass at integration complete. working on open case
    [assembly-util.scad, assembly.scad, column-layout.scad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]
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2021-10-21 hull triangulation heuristic in effect for avoiding plate protrusions
    [column-layout.scad, column-util.scad, util.scad]
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2021-11-12 tuned mounting tolerances and added mount for rubber feet
    [util.scad]
2021-11-12 change order of applying tent and tilt so we have a pre and post z rotation option
    [column-util.scad]
2021-11-12 first fully wired prototype. thumb needs to be adjusted but looking good
    [assembly.scad]
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2021-11-20 add ability to protect trackpoint stem from shearing with a cylindrical shield
    [trackpoint.scad]
2021-11-20 palmrest now has feet and magnet, magnet holder bores a channel for washers and nuts.
    [rest.scad, util.scad]
2021-11-20 increase tenting, move thumb back, in and lower, adjust fingers
    [assembly.scad, util.scad]
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2021-11-30 make extra room around keywell configurable on a per-key basis
    [column-layout.scad]
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2021-12-02 make it easier to screw in tp extension set screws
    [trackpoint.scad]
2021-12-02 fix trackpoint mount preview
    [trackpoint.scad]
2022-02-12 convert keycap render settings to functions from special vars
    [keycap.scad, settings.scad]
2022-04-08 new wall generator with configurable extra room and multiple artiulations per key
    [column-layout.scad, column-util.scad, settings.scad]
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2022-04-08 missing file
    [keywell.scad]
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2022-10-06 fix teensy mount for left hand and TRRS for deeper plates
    [util.scad]
2022-10-06 allow magnet mount to be extended in up to 3 directions
    [util.scad]
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2022-10-11 allow override for column-first placement, factor out cancel_rotation(), and allow tent to be overriden
    [column-util.scad]
2022-10-11 add helpers for renders and discuss in Usage
    [fingers.scad, plate.scad, thumb.scad]
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2022-11-10 arc placement style - circular in the XY plane
    [column-util.scad]
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2023-02-22 test prints for various key placements. also used as regression tests.
    [cylindrical-tester.scad, flat-tester.scad, offset-tester.scad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]
2023-02-22 an scad wrapper for diffing a column tester and a previous .stl
    its a bit odd. I take the intersection of the two, hoping for an empty object. but success is when rendering fails with no top level object. openscad won't spit out an empty .stl
    [wrapper.scad]
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2023-02-22 a python script for regression testing using the 'tester' modules I've created to try out different column feels
    [wrapper.scad]
2023-02-22 for now, only test by intersecting two .stls, not an openscad model with a reference .stl
    [wrapper.scad]
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2023-02-22 support wall flush with switch mount hole. fix wall topper model (and associated bounding box).
    supports angled wall topper as well, but this support is not exposed with a setting.
    [keywell.scad]
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2023-02-22 rename flat tester to reflect that it is now a full half of a split ortho keyboard and introduce flat-cherry tester to fill the role of the original flat tester: serve as a print insure that the flat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
    [flat-cherry-tester.scad, split-ortho-tester.scad]
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2023-02-22 replace all globals with functions, which allow overrides with a special var (prefixed with $).
    switch to use <settings.scad> instead of include<>. functions prepare us for adding choc support.
    [assembly.scad, cap.scad, cylindrical-tester.scad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]
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2023-02-23 fix rest include
    [rest.scad]
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2023-03-11 add optional overhead extension to trackpoint mount. allows for attachment above the trackpoint rather than next to adjointing keys
    [trackpoint.scad]
2023-03-11 auto-extend vectors, so that you don't need to repeat identical values multiple times in placement data structures.
    [util.scad]
2023-03-11 introduce punch_holes column layout feature, because LPX key mounts can get so close they impinge on each others cavities, or switch courtyards. this lays out slugs and then removes cavities as a sec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
    not enabled by default because the coplanar cubes used to remove obstructions above and below the mount are exactly the sort of thing that leads openscad to generate non-manifold .stls.
    [layout.scad, mount.scad]
2023-03-12 fix corners for simple walls. breaking change for split-ortho-tester.
    [layout.scad]
2023-03-19 be explicit about fn for the spheres and cylinders used for key mound connectors and walls
    [mount.scad]
2023-03-19 setting for mx speed switches with shorter total travel
    [settings.scad]
2023-06-03 support absolute positioning of support struts, along with 0 length mountings
    [util.scad]
2023-06-03 convenience function for applying arrays of strut mounts
    [util.scad]
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2023-06-21 properly join wall corners on intersections between catty-corner keys
    [layout.scad]
2023-06-21 tighten choc mount
    [settings.scad]
2023-06-21 mx_and_choc setting to use mounts compatible with both switch types. note, hole will be bigger that usual for chocs in order to accomodate mx switches as well
    [mount.scad, settings.scad]
2023-06-21 chocs get independent settings for controlling key mount retention tab dimensions
    [mount.scad, settings.scad]
2023-06-21 narrowsides (walls flush with the mount hole, for faster prints of switch testers) should only override key mount header/footer/leftside/rightside when there is a wall that we are tucking under that 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
    [layout.scad]
2023-06-21 fix comment
    [util.scad]
2025-02-04 adjustable bracket for joining halves into a shoulder-width unsplit
    [unsplit-bracket.scad]
2025-02-04 add to bar magnet an optional hex shaped hole that conceals a hex nut and acts as a wrench to hole it in place
    [util.scad]
2025-02-04 tighten tolerances for mcu and trrs mounts
    [util.scad]
2025-02-04 add z param to adjust mcu and trrs mount heights, and remove_hole to extend the mcu diode cutout completely through that padding
    [util.scad]
2025-02-04 add choc hotswap model and cutout to switch mount
    [mount.scad]
2025-02-05 column layout can take a block with child objects (such as extra key plate connections). punch_holes applies to these objects as well.
    [layout.scad]
2025-02-05 [breaking] switch tilt and offset to column major per-key array lookup, also allow per-key specification of tent, position and displacement
    [util.scad]
2025-02-05 for circular placements, a displacement of a homerow/homecol key should still produce a rotation, even though there is no rotation from the placement function
    [util.scad]
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2026-06-15 tighten camera mount tolerance
    [tripod.scad]
2026-06-16 correct round magnet dimensions
    [util.scad]
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
